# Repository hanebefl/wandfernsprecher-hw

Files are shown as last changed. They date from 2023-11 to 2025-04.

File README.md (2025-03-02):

# GSM Wandfernsprecher
GSM conversion PCB for an old German wall-mounted telephone.

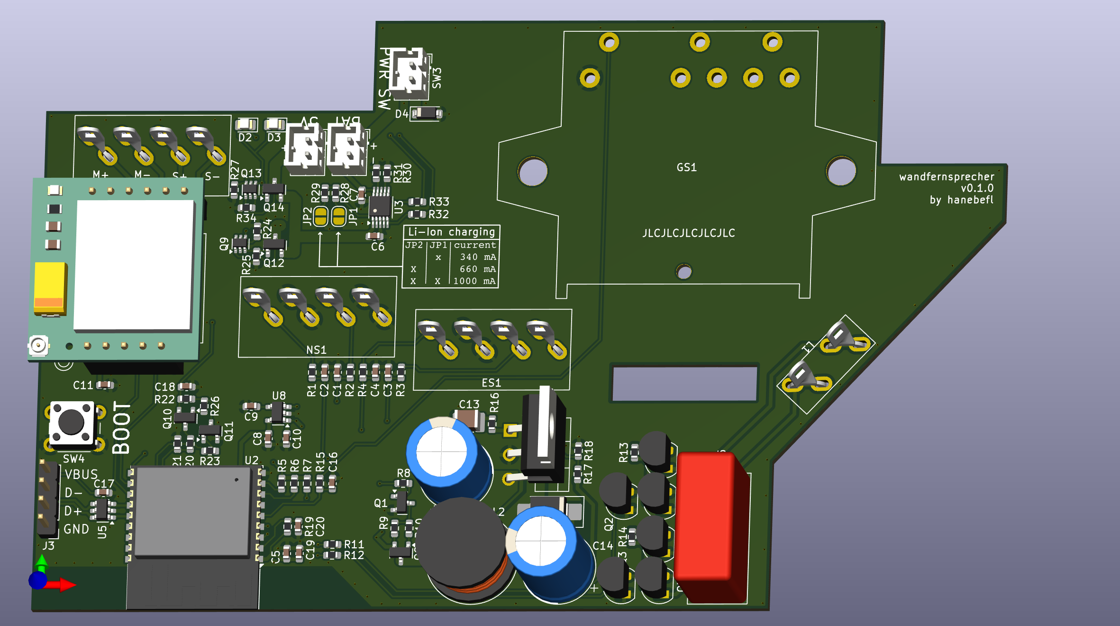
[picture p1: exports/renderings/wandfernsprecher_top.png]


This project uses a SIM800L GSM module, and is controlled by a ESP32-C3 running Micropython.

## Firmware Source Code
The firmware is located in a separate repository: [Wandfernsprecher Firmware](https://github.com/hanebefl/wandfernsprecher-fw)

## Directory Structure
| directory  | content |
|---|---|
| source | KiCad project directories |
| production | fabrication files (Gerber, BOM, placement) |
| exports | schematic and layout plots, board 3D model and renderings |
| datasheets | component datasheets |
| assets | board setups, component 3D models, logos |
| scripts | BOM export plugins, miscellaneous helper scripts for file conversion |
| hooks | git hooks, for example for automatic documentation export |

## Repository Template
Created with a [KiCAD project template](https://github.com/cyber-murmel/kicad-template) by [cyber-murmel](https://github.com/cyber-murmel)

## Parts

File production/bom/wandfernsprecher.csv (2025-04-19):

Designator | Footprint | Quantity | Value | LCSC Part #
C1,C2,C3,C4,C5,C11,C16,C10 | Capacitor_SMD:C_0603_1608Metric | 8 | 100nF
C17 | Capacitor_SMD:C_0603_1608Metric | 1 | 100n
C18,C20,C6,C7 | Capacitor_SMD:C_0603_1608Metric | 4 | 1µF
C19,C8 | Capacitor_SMD:C_0603_1608Metric | 2 | 10µF
D4 | Diode_SMD:D_SOD-123 | 1 | 5.1V
ES1 | FeWAp:CONN_01x04_vertical_mod | 1 | Erdschalter
GS1 | FeWAp:Gabelschalter | 1 | Gabelschalter
J1 | FeWAp:CONN_01x04_vertical_mod | 1 | Hörer
J3 | Connector_PinHeader_2.54mm:PinHeader_1x04_P2.54mm_Vertical | 1 | Conn_01x04
NS1 | FeWAp:CONN_01x04_vertical_mod | 1 | ~
Q10,Q8,Q12,Q14 | Package_TO_SOT_SMD:SOT-23 | 4 | AO3401A
Q11,Q15,Q1 | Package_TO_SOT_SMD:SOT-23 | 3 | AO3400A
R1,R2,R3,R4,R15 | Resistor_SMD:R_0603_1608Metric | 5 | 100
R5,R6,R7,R19,R21,R22,R9,R24,R25,R27,R31,R34 | Resistor_SMD:R_0603_1608Metric | 12 | 10k
R20 | Resistor_SMD:R_0603_1608Metric | 1 | 12k
R23,R26,R35,R8,R10,R16,R30 | Resistor_SMD:R_0603_1608Metric | 7 | 1k
SW4 | Button_Switch_THT:SW_PUSH_6mm | 1 | BOOT
U1 | FeWAp:SIM800L-module | 1 | SIM800L
U2 | RF_Module:ESP32-C3-WROOM-02 | 1 | ESP32-C3-WROOM-02
U5 | Package_TO_SOT_SMD:SOT-23-6 | 1 | USBLC6-2SC6
C12 | Capacitor_THT:CP_Radial_D10.0mm_P5.00mm | 1 | 100µF
C13 | Capacitor_SMD:C_1210_3225Metric_Pad1.33x2.70mm_HandSolder | 1 | 1µF
C14 | Capacitor_THT:CP_Radial_D10.0mm_P5.00mm | 1 | 220µF
C15 | Capacitor_THT:C_Rect_L18.0mm_W8.0mm_P15.00mm_FKS3_FKP3 | 1 | 1µF
D1 | Diode_SMD:D_SMB_Handsoldering | 1 | MBRS1100T3
L1 | FeWAp:CONN_01x02_vertical_mod | 1 | ~
L2 | Inductor_THT:L_Radial_D12.5mm_P7.00mm_Fastron_09HCP | 1 | L
Q2,Q3,Q4,Q6 | Package_TO_SOT_THT:TO-92_HandSolder | 4 | 2N5551
Q5,Q7 | Package_TO_SOT_THT:TO-92_HandSolder | 2 | 2N5401
R11,R12 | Resistor_SMD:R_0603_1608Metric | 2 | 2k2
R13,R14 | Resistor_SMD:R_0603_1608Metric | 2 | 47k
R17 | Resistor_SMD:R_0603_1608Metric | 1 | 68k
R18 | Resistor_SMD:R_0603_1608Metric | 1 | 1k8
U4 | Package_TO_SOT_THT:TO-220-5_P3.4x3.7mm_StaggerOdd_Lead3.8mm_Vertical | 1 | LT1170CT
BT1 | Connector_JST:JST_PH_B2B-PH-K_1x02_P2.00mm_Vertical | 1 | Battery_Cell
C9 | Capacitor_SMD:C_0603_1608Metric | 1 | 10nF
D2 | LED_SMD:LED_0805_2012Metric | 1 | GRN
D3 | LED_SMD:LED_0805_2012Metric | 1 | YEL
J2 | Connector_JST:JST_PH_B2B-PH-K_1x02_P2.00mm_Vertical | 1 | Vin
Q9,Q13 | Package_TO_SOT_SMD:SOT-363_SC-70-6 | 2 | BC857BS
R28,R32,R33 | Resistor_SMD:R_0603_1608Metric | 3 | 1k6
R29 | Resistor_SMD:R_0603_1608Metric | 1 | 820
SW3 | Connector_JST:JST_PH_B2B-PH-K_1x02_P2.00mm_Vertical | 1 | SW_SPST
U3 | Package_SO:HVSSOP-10-1EP_3x3mm_P0.5mm_EP1.57x1.88mm_ThermalVias | 1 | BQ24090DGQ
U8 | Package_TO_SOT_SMD:SOT-23-5 | 1 | TPS73633DBV

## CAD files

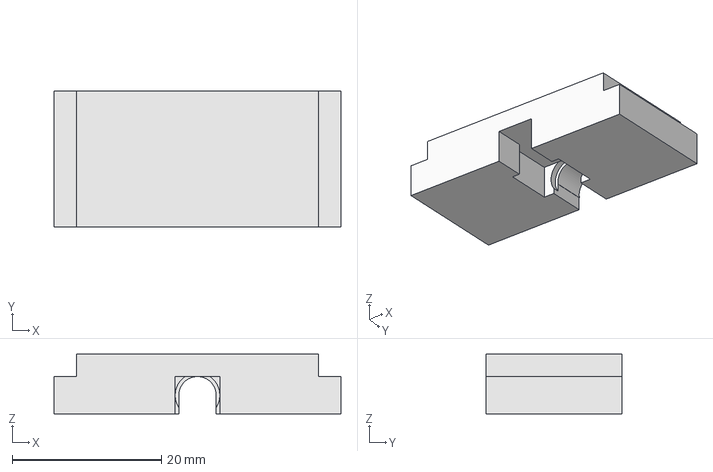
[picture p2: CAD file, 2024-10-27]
assets/3D models/FeWAp_switch_holder.FCStd
38.5 x 18.3 x 8.00 mm

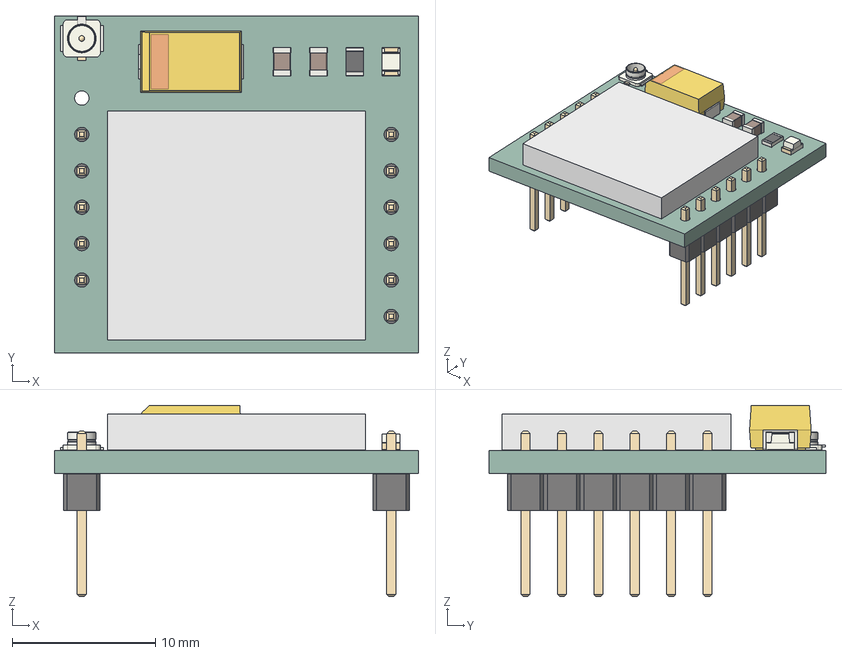
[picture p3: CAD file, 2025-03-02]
assets/SIM800-model/SIM800L-module.step
25.4 x 23.5 x 13.3 mm
LED_0805_2012Metric
R_0805_2012Metric
C_0805_2012Metric x 2
CP_EIA_7343_31_Kemet_D
U.FL_Hirose_U.FL-R-SMT-1_Vertical
PinHeader_1x05_P254mm_Vertical
PinHeader_1x06_P254mm_Vertical
sim800-model_PCB

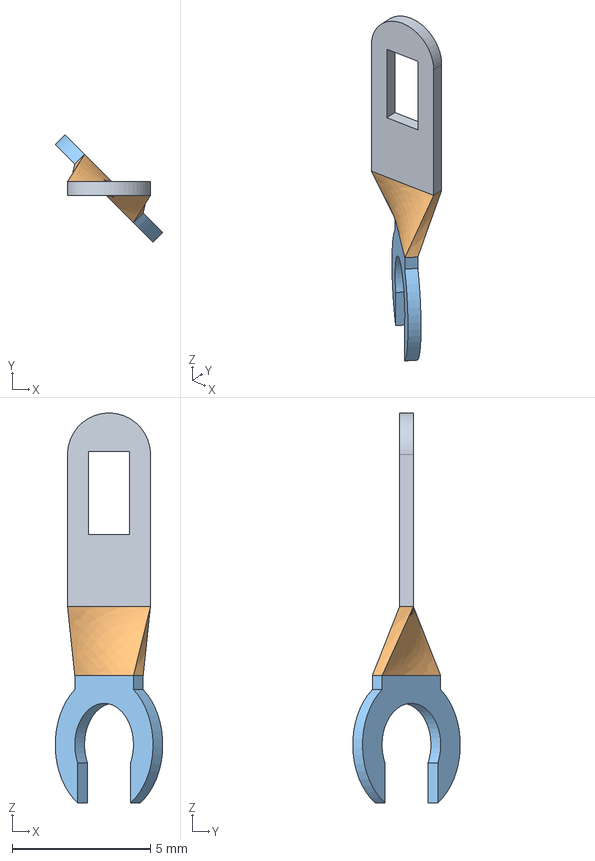
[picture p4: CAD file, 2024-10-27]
assets/3D models/pin_mod.step
3.89 x 3.89 x 14.1 mm

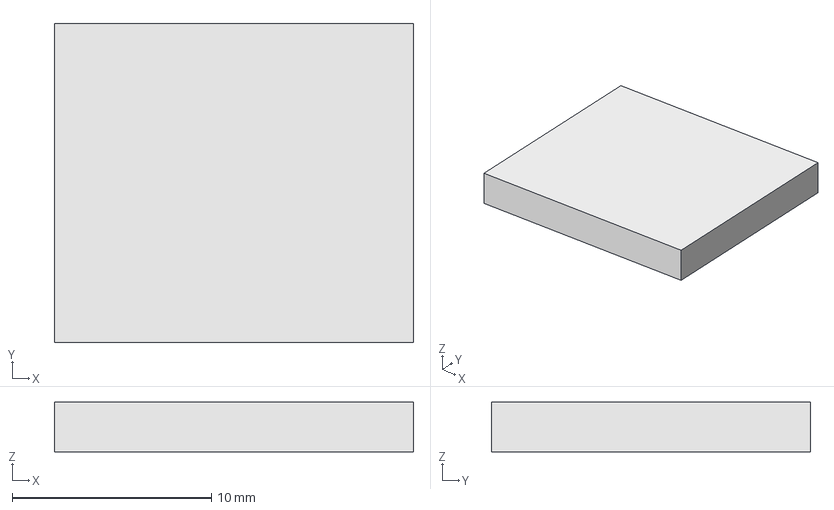
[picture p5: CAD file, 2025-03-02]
assets/SIM800-model/shield.step
18.0 x 16.0 x 2.50 mm

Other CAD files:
assets/3D models/pin-mod.FCStd
assets/3D models/pin_mod.stl

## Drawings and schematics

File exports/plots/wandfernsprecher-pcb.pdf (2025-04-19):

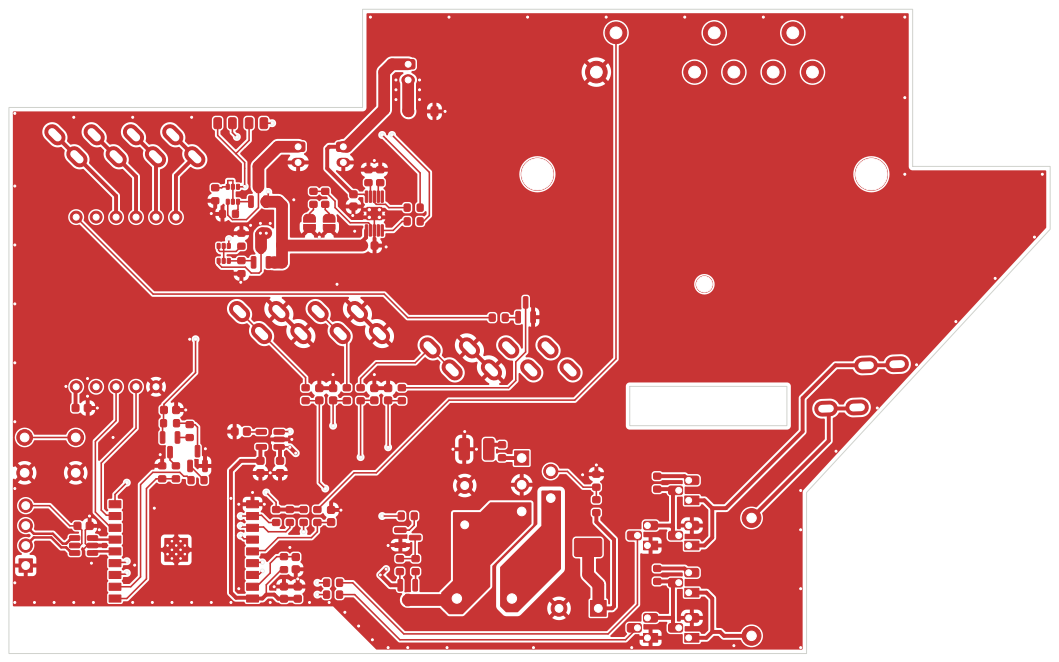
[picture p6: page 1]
D Date: 2024-11-01 KiCad; E.D.A. 8.0.9 Size: A4; Rev: 0.1.1; Id: 1/1 Title: Wandfernsprecher File: wandfernsprecher.kicad_pcb Sheet: author:; hanebefl Copyright; hanebefl (https://github.com/hanebefl)

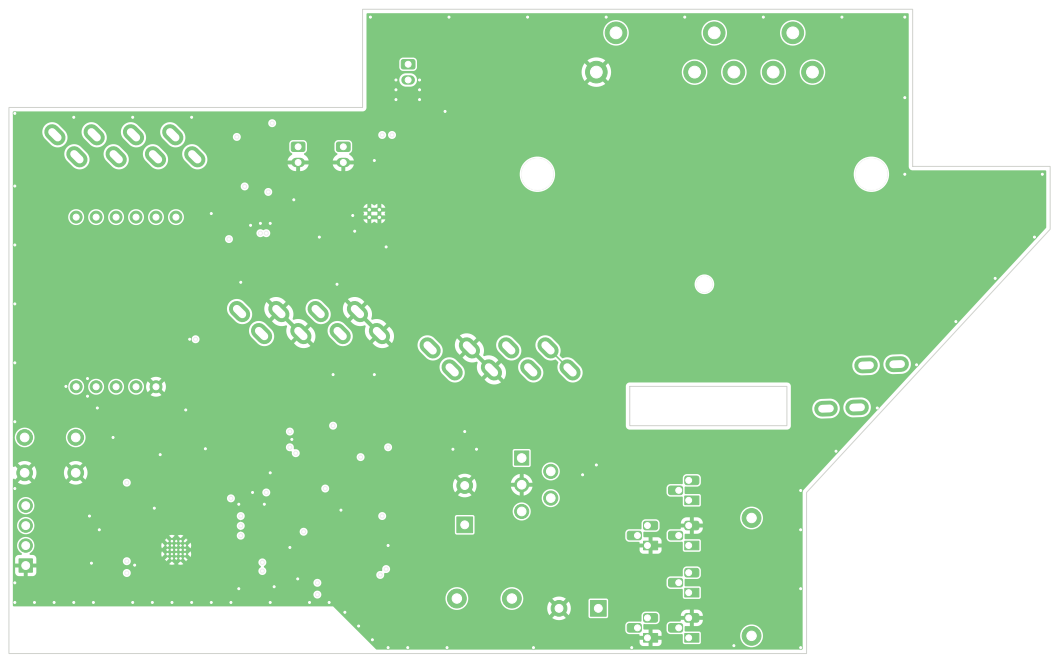
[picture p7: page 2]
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

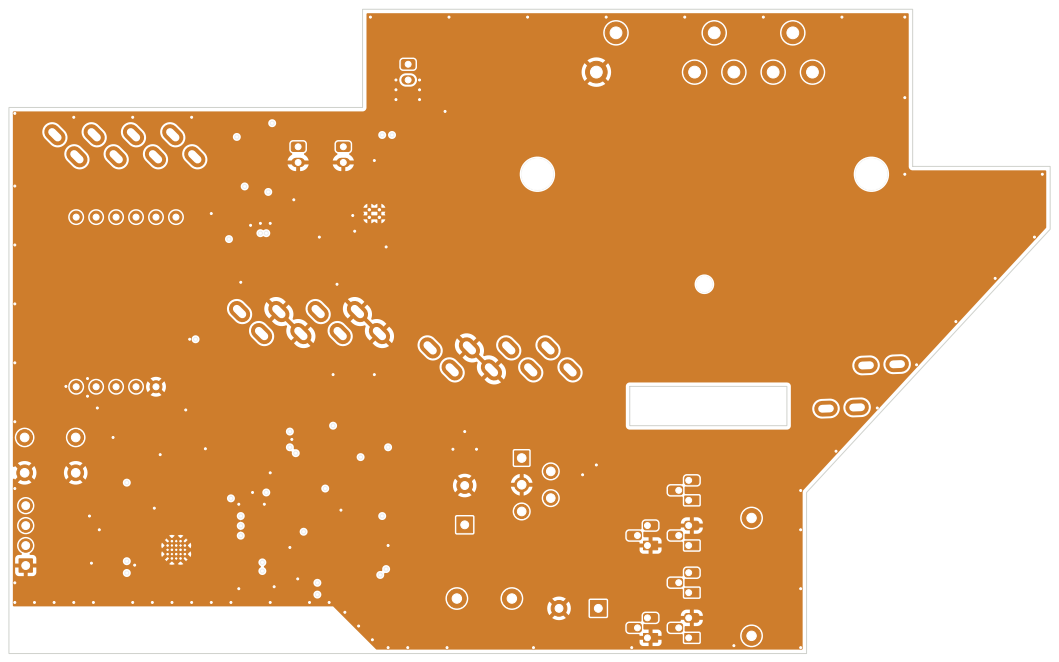
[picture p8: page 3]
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

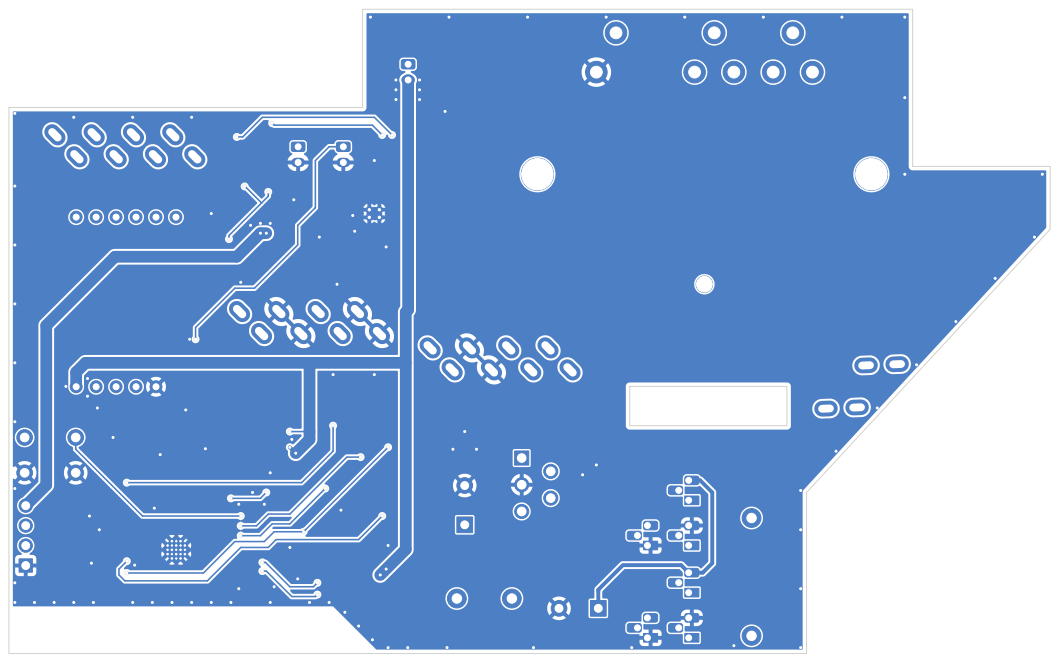
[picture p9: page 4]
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

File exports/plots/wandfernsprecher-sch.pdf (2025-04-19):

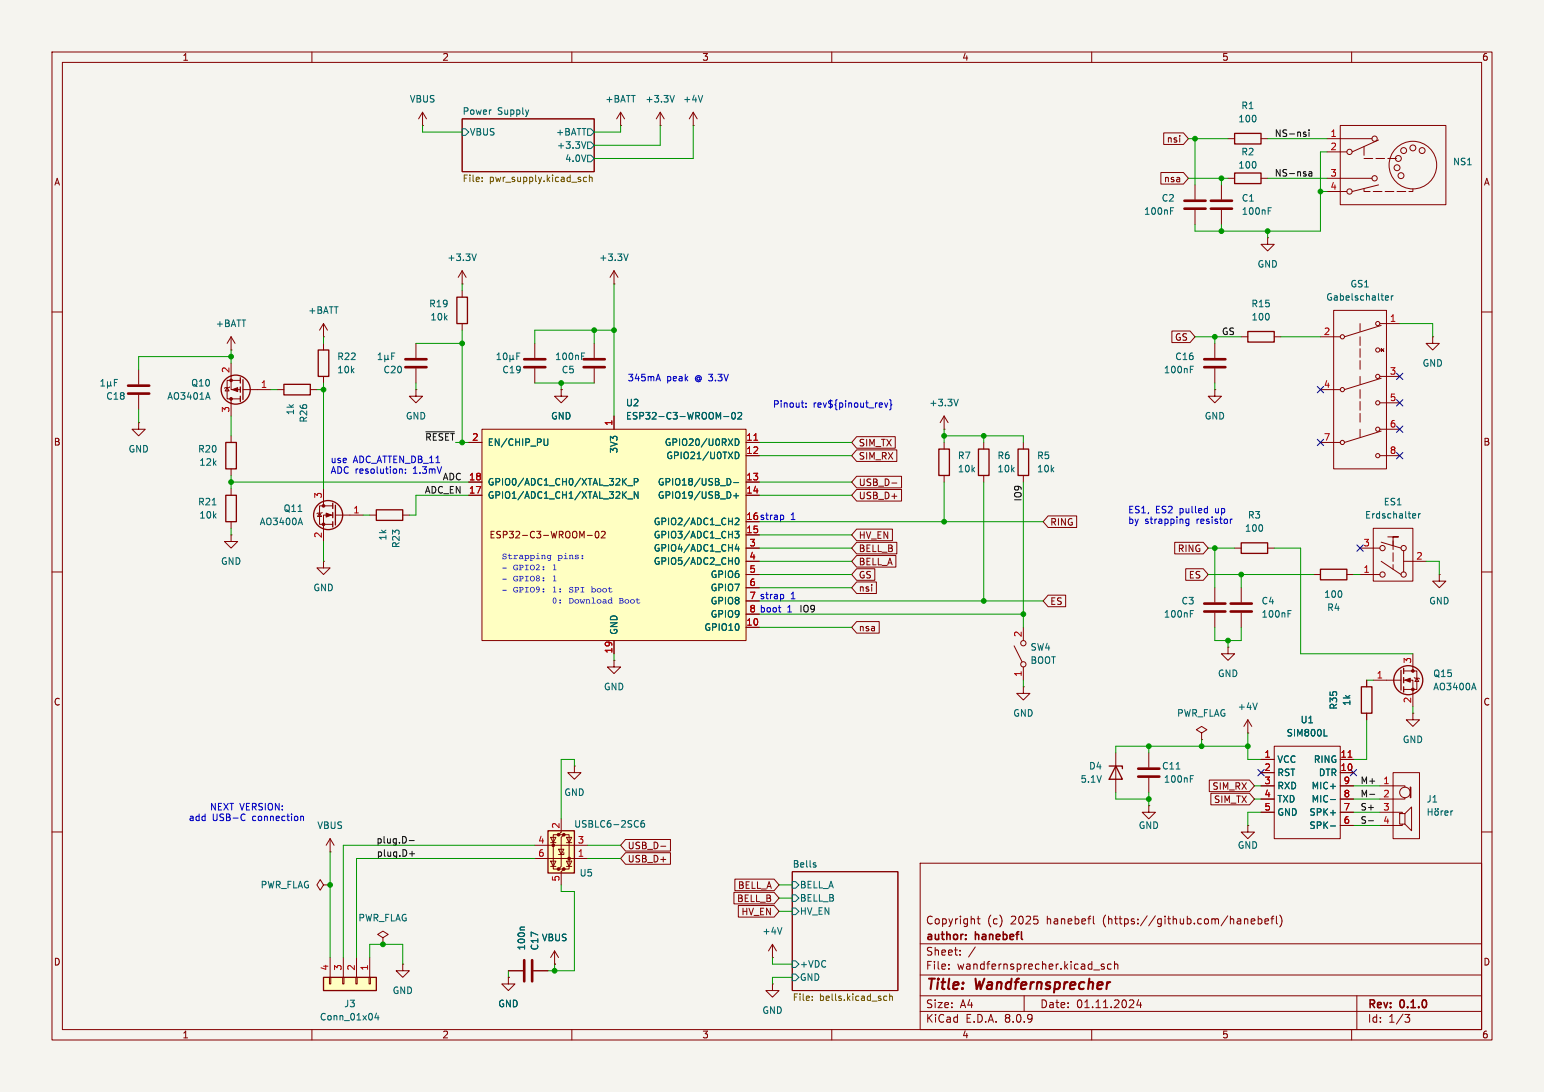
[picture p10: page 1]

- GPIO9: 1: SPI boot 0: Download Boot VBUS 100n C17 GND

1 GPIO10 10 GPIO20/U0RXD 11 GPIO21/U0TXD 12 GPIO18/USB_D- 13 GPIO19/USB_D+ 14 GPIO3/ADC1_CH3 15 GPIO2/ADC1_CH2 16 GPIO1/ADC1_CH1/XTAL_32K_N 17 GPIO0/ADC1_CH0/XTAL_32K_P 18 GND 19 EN/CHIP_PU 2 GPIO4/ADC1_CH4 3 GPIO5/ADC2_CH0 4 GPIO6 5 GPIO7 6 GPIO8 7 GPIO9 8 U2ESP32-C3-WROOM-02 GND GND

1 GPIO10 10 GPIO20/U0RXD 11 GPIO21/U0TXD 12 GPIO18/USB_D- 13 GPIO19/USB_D+ 14 GPIO3/ADC1_CH3 15 GPIO2/ADC1_CH2 16 GPIO1/ADC1_CH1/XTAL_32K_N 17 GPIO0/ADC1_CH0/XTAL_32K_P 18 GND 19 EN/CHIP_PU 2 GPIO4/ADC1_CH4 3 GPIO5/ADC2_CH0 4 GPIO6 5 GPIO7 6 GPIO8 7 GPIO9 8 R35 1k U1 SIM800L VCC 1 DTR 10 RING 11 RST 2 RXD 3 TXD 4 GND 5 SPK- 6 SPK+ 7 MIC- 8 MIC+ 9

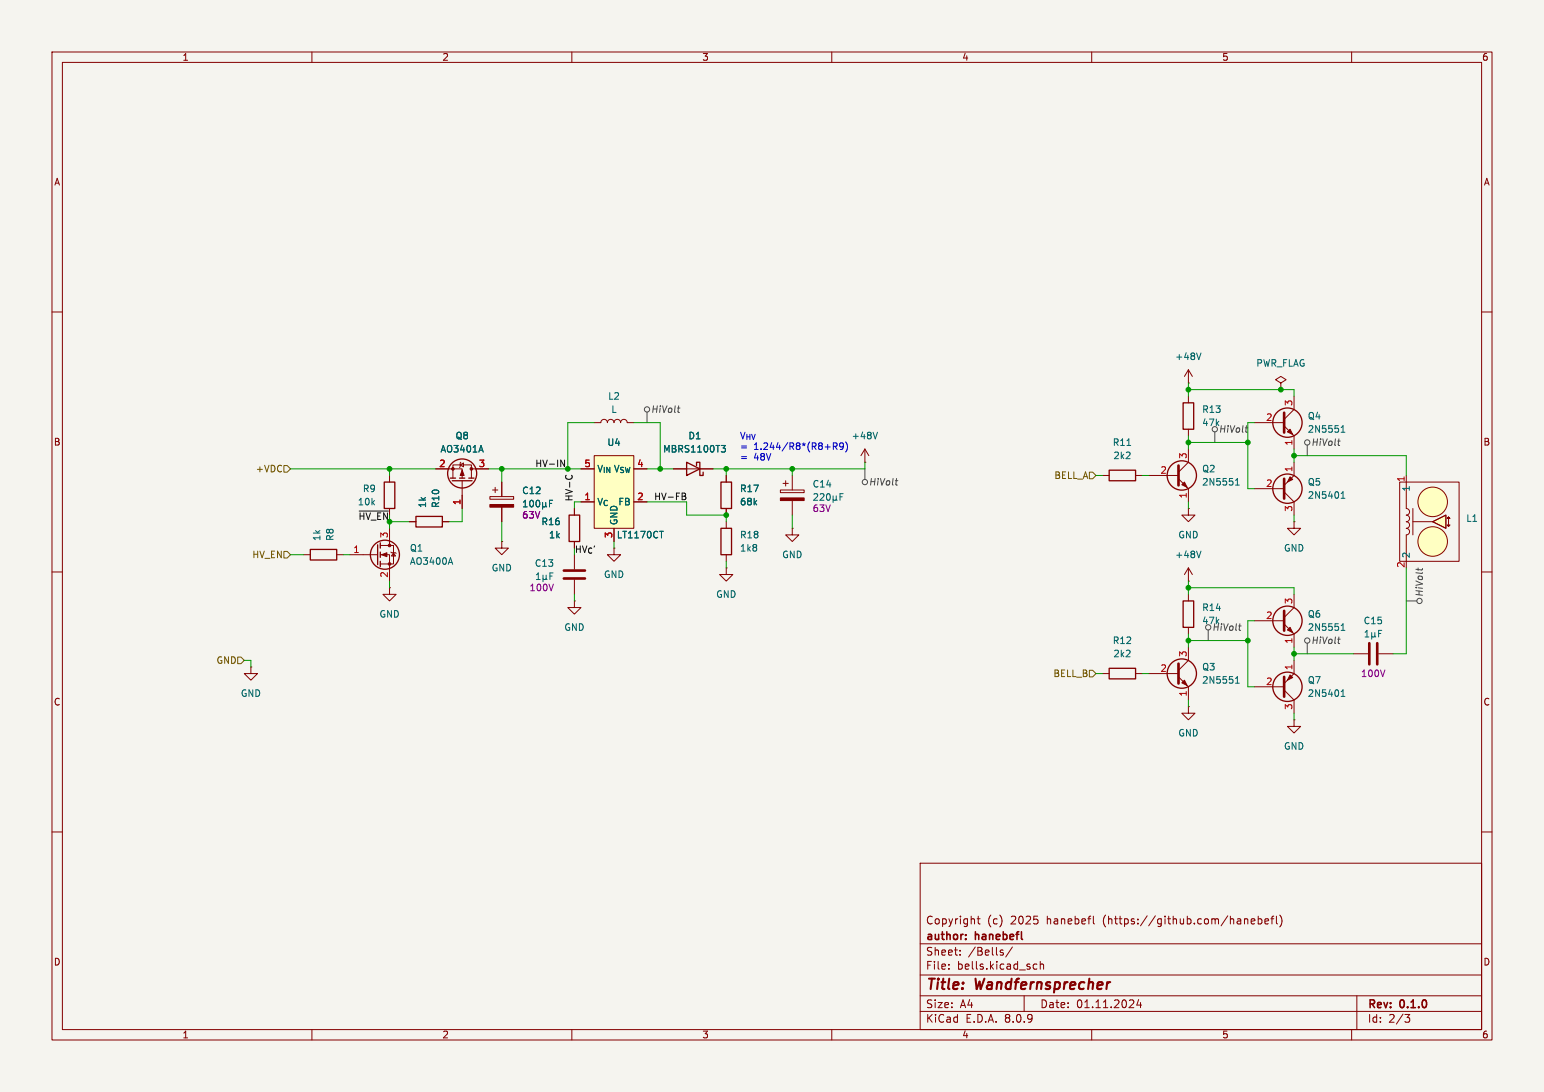
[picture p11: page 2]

BELL_A HV-FB HV-IN HV-C

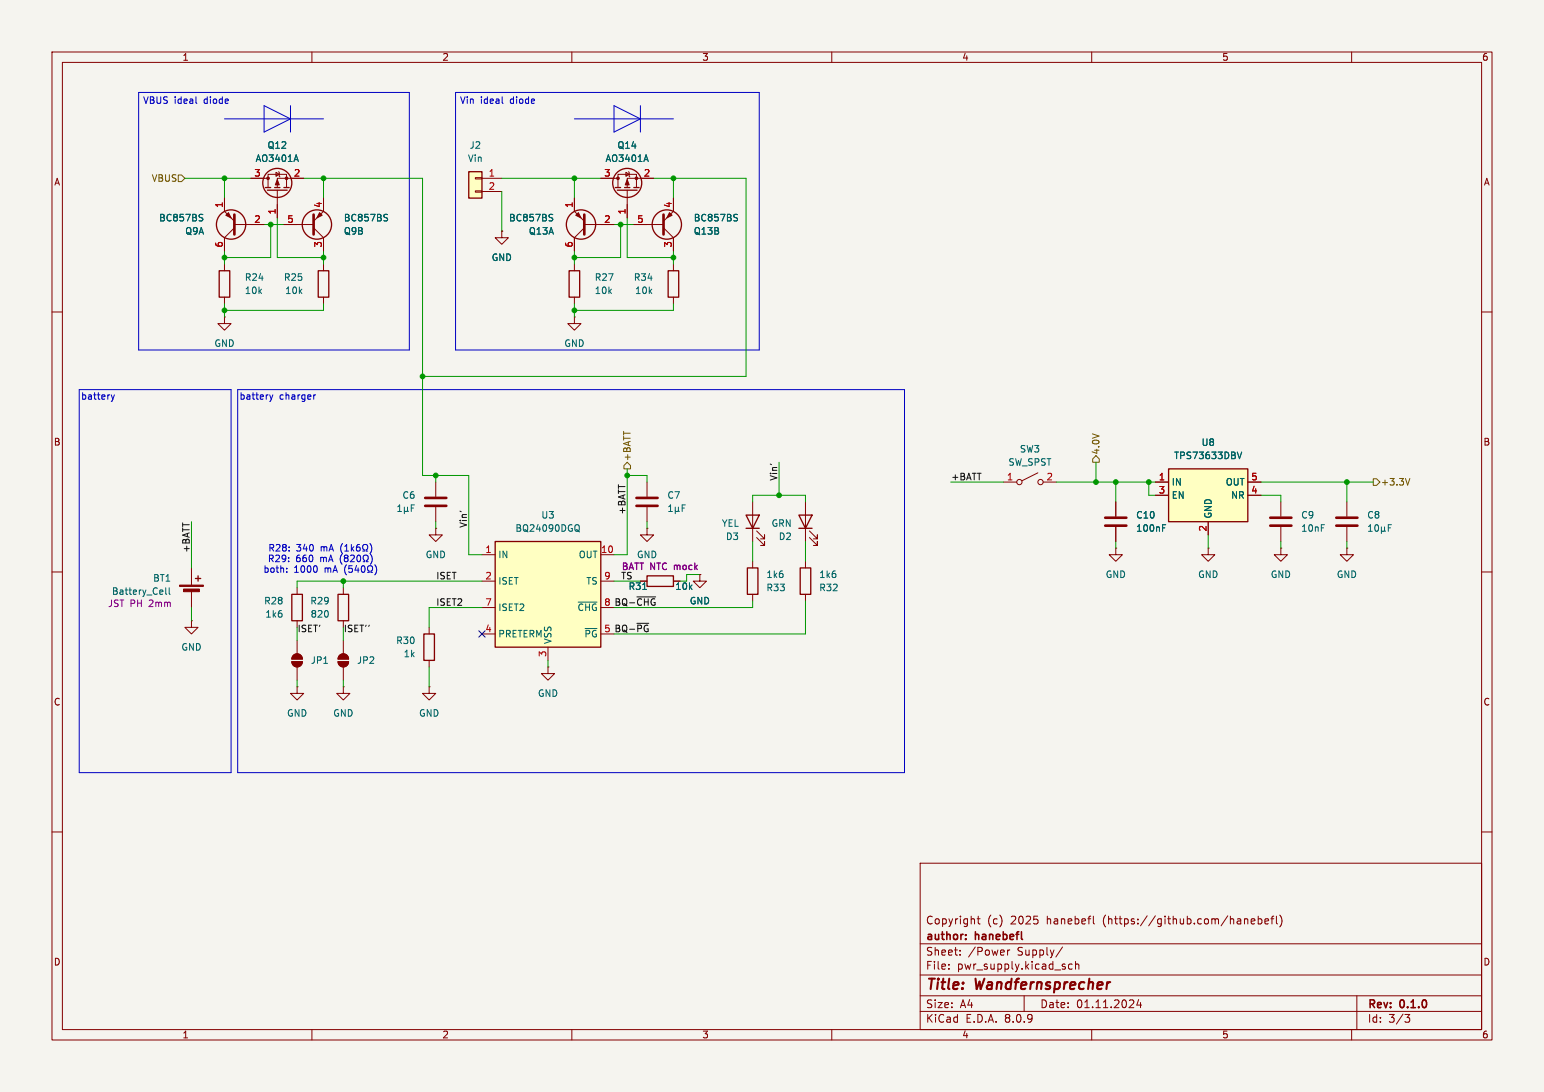
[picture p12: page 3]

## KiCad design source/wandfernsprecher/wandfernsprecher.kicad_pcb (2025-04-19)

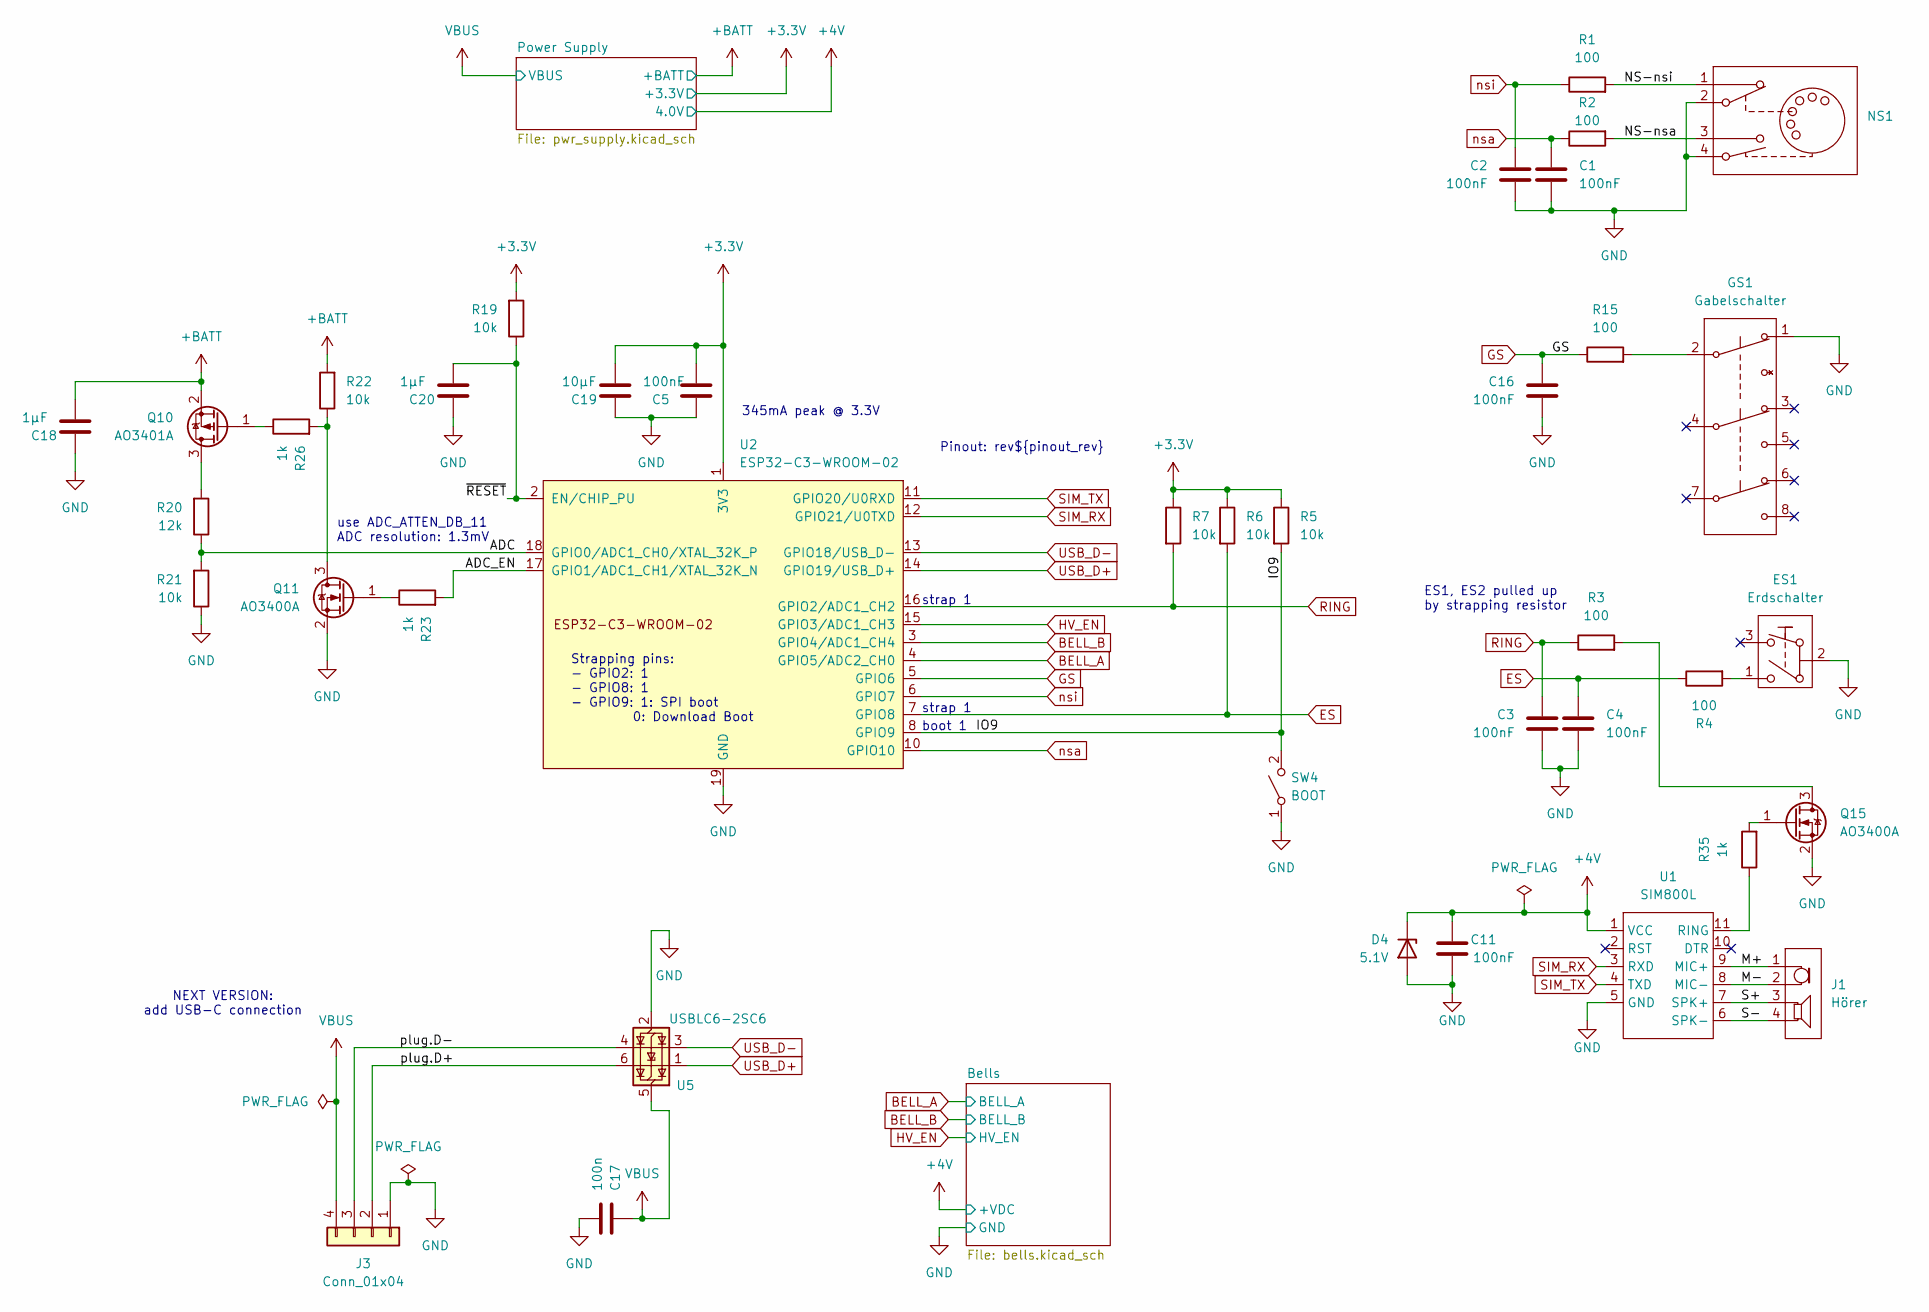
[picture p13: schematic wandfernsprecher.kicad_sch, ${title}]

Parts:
C1, C2, C3, C4, C5, C11, C16: 100nF; C_0603_1608Metric
C17: 100n; C_0603_1608Metric
C18, C20: 1µF; C_0603_1608Metric
C19: 10µF; C_0603_1608Metric
D4: 5.1V; D_SOD-123
ES1: Erdschalter; CONN_01x04_vertical_mod
GS1: Gabelschalter
J1: Hörer; CONN_01x04_vertical_mod
J3: Conn_01x04; PinHeader_1x04_P2.54mm_Vertical
NS1: CONN_01x04_vertical_mod
Q10: AO3401A; SOT-23
Q11, Q15: AO3400A; SOT-23
R1, R2, R3, R4, R15: 100; R_0603_1608Metric
R5, R6, R7, R19, R21, R22: 10k; R_0603_1608Metric
R20: 12k; R_0603_1608Metric
R23, R26, R35: 1k; R_0603_1608Metric
SW4: BOOT; SW_PUSH_6mm
U1: SIM800L; SIM800L-module
U2: ESP32-C3-WROOM-02
U5: USBLC6-2SC6; SOT-23-6

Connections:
+3.3V: C5.2, C19.2, R5.1, R6.1, R7.1, R19.2, U2.1 (3V3); also elsewhere on the board
+4V: C11.1, D4.1 (K), U1.1 (VCC); also elsewhere on the board
+BATT: C18.2, Q10.2 (S), R22.2; also elsewhere on the board
/ADC: R20.1, R21.2, U2.18 (GPIO0/ADC1_CH0/XTAL_32K_P)
/ADC_EN: R23.2, U2.17 (GPIO1/ADC1_CH1/XTAL_32K_N)
/IO9: R5.2, SW4.2 (B), U2.8 (GPIO9)
/M+: J1.1 (SPK+), U1.9 (MIC+)
/M-: J1.2 (SPK-), U1.8 (MIC-)
/NS-nsa: NS1.3 (E1), R2.2
/NS-nsi: NS1.1 (N1), R1.2
/S+: J1.3 (MIC+), U1.7 (SPK+)
/S-: J1.4 (MIC-), U1.6 (SPK-)
/plug.D+: J3.2, U5.6 (I/O1)
/plug.D-: J3.3, U5.4 (I/O2)
/~RESET: C20.2, R19.1, U2.2 (EN/CHIP_PU)
BELL_A: U2.4 (GPIO5/ADC2_CH0); also elsewhere on the board
BELL_B: U2.3 (GPIO4/ADC1_CH4); also elsewhere on the board
ES: C4.1, R4.1, R6.2, U2.7 (GPIO8)
GND: C1.2, C2.2, C3.2, C4.2, C5.1, C11.2, C16.2, C17.2, C18.1, C19.1, C20.1, D4.2 (A), ES1.2 (B), GS1.1 (S1l), J3.1, NS1.2 (N2), NS1.4 (E2), Q11.2 (S), Q15.2 (S), R21.1, SW4.1 (A), U1.5 (GND), U2.9 (GND), U2.19 (GND), U5.2 (GND); also elsewhere on the board
GS: C16.1, R15.1, U2.5 (GPIO6)
HV_EN: U2.15 (GPIO3/ADC1_CH3); also elsewhere on the board
unnamed: ES1.1 (A), R4.2
unnamed: GS1.2 (S1c), R15.2
unnamed: Q10.3 (D), R20.2
unnamed: Q10.1 (G), R26.1
unnamed: Q11.3 (D), R22.1, R26.2
unnamed: Q11.1 (G), R23.1
unnamed: Q15.3 (D), R3.2
unnamed: Q15.1 (G), R35.2
unnamed: R35.1, U1.11 (RING)
RING: C3.1, R3.1, R7.2, U2.16 (GPIO2/ADC1_CH2)
SIM_RX: U1.3 (RXD), U2.12 (GPIO21/U0TXD)
SIM_TX: U1.4 (TXD), U2.11 (GPIO20/U0RXD)
USB_D+: U2.14 (GPIO19/USB_D+), U5.1 (I/O1)
USB_D-: U2.13 (GPIO18/USB_D-), U5.3 (I/O2)
VBUS: C17.1, J3.4, U5.5 (VBUS); also elsewhere on the board
nsa: C1.1, R2.1, U2.10 (GPIO10)
nsi: C2.1, R1.1, U2.6 (GPIO7)

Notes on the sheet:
NEXT VERSION: add USB-C connection
Pinout: rev${pinout_rev}
strap 1
boot 1
ES1, ES2 pulled up by strapping resistor
Strapping pins: - GPIO2: 1 - GPIO8: 1 - GPIO9: 1: SPI boot 0: Download Boot
345mA peak @ 3.3V
use ADC_ATTEN_DB_11 ADC resolution: 1.3mV

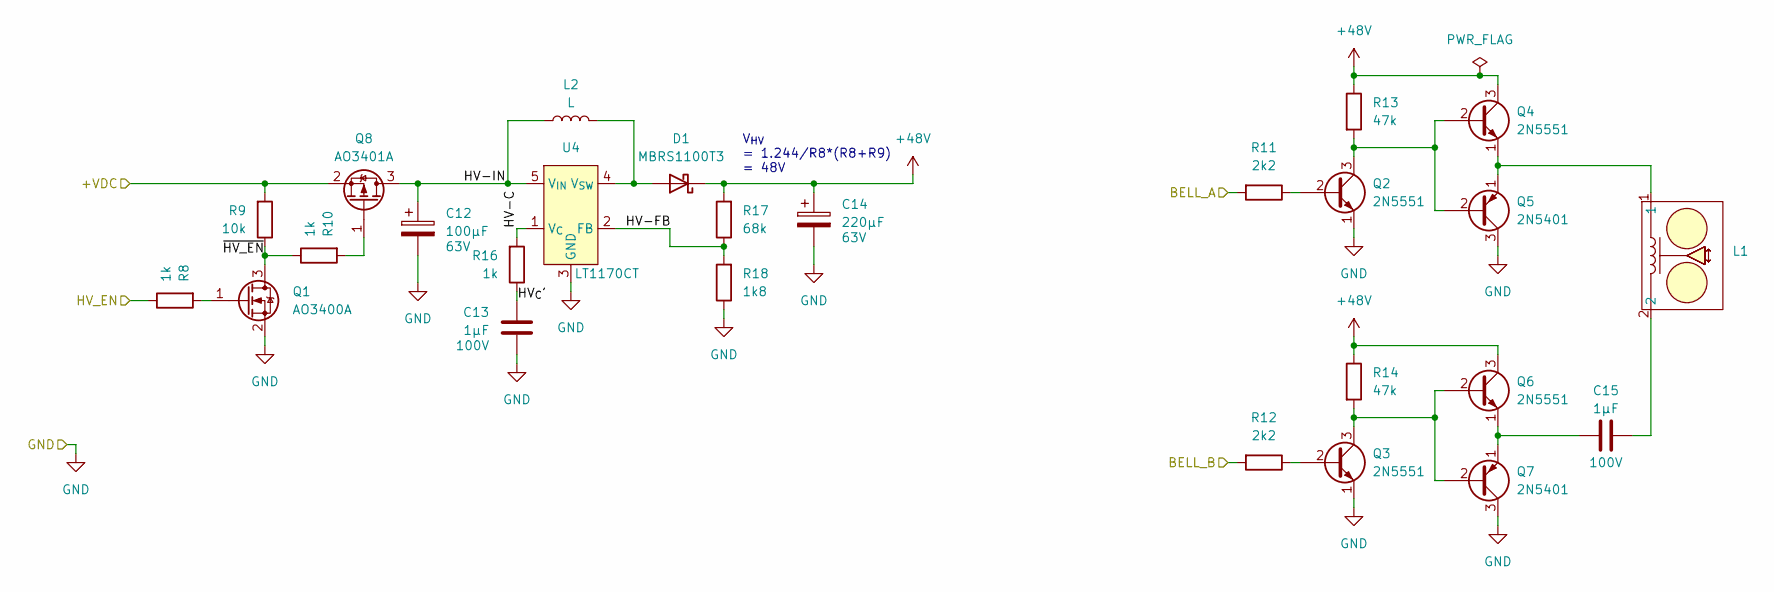
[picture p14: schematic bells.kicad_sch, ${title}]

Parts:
C12: 100µF; CP_Radial_D10.0mm_P5.00mm; Voltage 63V
C13: 1µF; C_1210_3225Metric_Pad1.33x2.70mm_HandSolder; Voltage 100V
C14: 220µF; CP_Radial_D10.0mm_P5.00mm; Voltage 63V
C15: 1µF; C_Rect_L18.0mm_W8.0mm_P15.00mm_FKS3_FKP3; Voltage 100V
D1: MBRS1100T3; D_SMB_Handsoldering
L1: CONN_01x02_vertical_mod
L2: L; L_Radial_D12.5mm_P7.00mm_Fastron_09HCP
Q1: AO3400A; SOT-23
Q2, Q3, Q4, Q6: 2N5551; TO-92_HandSolder
Q5, Q7: 2N5401; TO-92_HandSolder
Q8: AO3401A; SOT-23
R8, R10, R16: 1k; R_0603_1608Metric
R9: 10k; R_0603_1608Metric
R11, R12: 2k2; R_0603_1608Metric
R13, R14: 47k; R_0603_1608Metric
R17: 68k; R_0603_1608Metric
R18: 1k8; R_0603_1608Metric
U4: LT1170CT; TO-220-5_P3.4x3.7mm_StaggerOdd_Lead3.8mm_Vertical

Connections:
+4V: Q8.2 (S), R9.2; also elsewhere on the board
+48V: C14.1, D1.1 (K), Q4.3 (C), Q6.3 (C), R13.1, R14.1, R17.2
/Bells/HV-C: R16.2, U4.1 (V_{C})
/Bells/HV-FB: R17.1, R18.2, U4.2 (FB)
/Bells/HV-IN: C12.1, L2.1, Q8.3 (D), U4.5 (V_{IN})
/Bells/HV_{C}': C13.1, R16.1
/Bells/~HV_EN: Q1.3 (D), R9.1, R10.1
BELL_A: R11.2; also elsewhere on the board
BELL_B: R12.2; also elsewhere on the board
GND: C12.2, C13.2, C14.2, Q1.2 (S), Q2.1 (E), Q3.1 (E), Q5.3 (C), Q7.3 (C), R18.1, U4.3 (GND); also elsewhere on the board
HV_EN: R8.1; also elsewhere on the board
unnamed: C15.2, L1.2
unnamed: D1.2 (A), L2.2, U4.4 (V_{SW})
unnamed: Q1.1 (G), R8.2
unnamed: Q2.2 (B), R11.1
unnamed: Q2.3 (C), Q4.2 (B), Q5.2 (B), R13.2
unnamed: Q3.2 (B), R12.1
unnamed: Q3.3 (C), Q6.2 (B), Q7.2 (B), R14.2
unnamed: L1.1, Q4.1 (E), Q5.1 (E)
unnamed: C15.1, Q6.1 (E), Q7.1 (E)
unnamed: Q8.1 (G), R10.2

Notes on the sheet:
V_{HV} = 1.244/R8*(R8+R9) = 48V

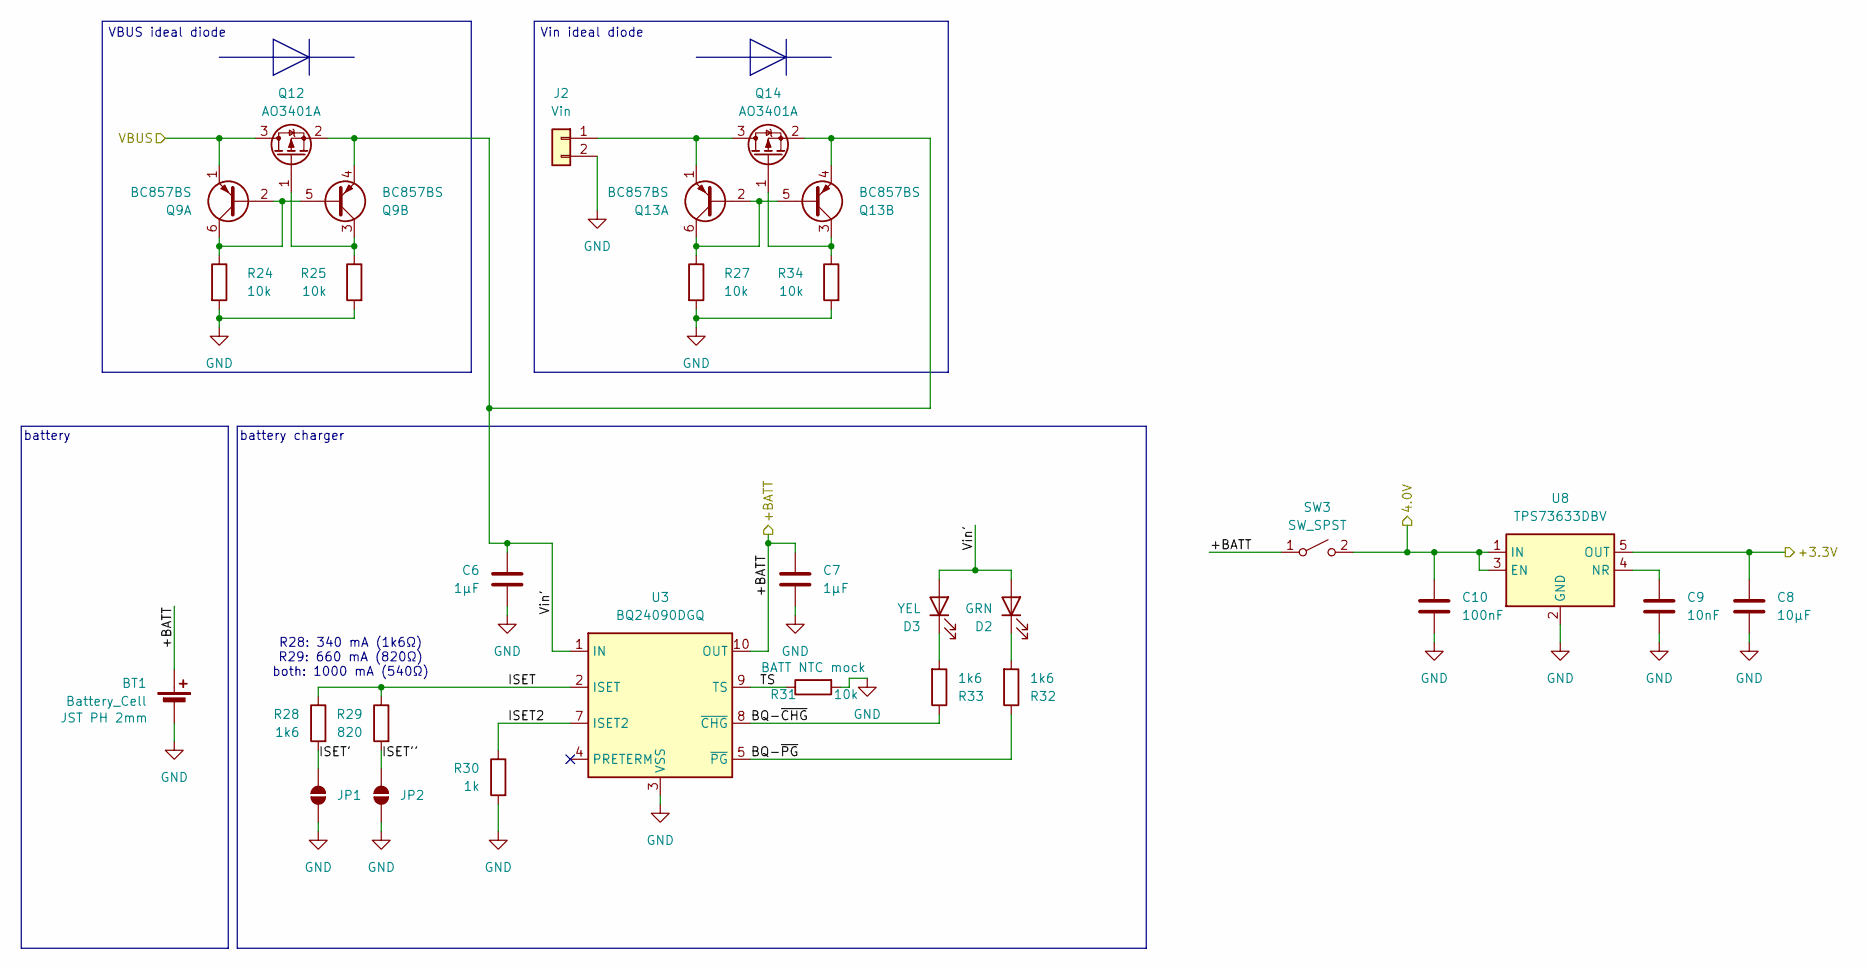
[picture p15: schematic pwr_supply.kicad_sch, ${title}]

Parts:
BT1: Battery_Cell; JST_PH_B2B-PH-K_1x02_P2.00mm_Vertical
C6, C7: 1µF; C_0603_1608Metric
C8: 10µF; C_0603_1608Metric
C9: 10nF; C_0603_1608Metric
C10: 100nF; C_0603_1608Metric
D2: GRN; LED_0805_2012Metric
D3: YEL; LED_0805_2012Metric
J2: Vin; JST_PH_B2B-PH-K_1x02_P2.00mm_Vertical
JP1, JP2: SolderJumper_2_Open; SolderJumper-2_P1.3mm_Open_RoundedPad1.0x1.5mm
Q9, Q13: BC857BS; SOT-363_SC-70-6
Q12, Q14: AO3401A; SOT-23
R24, R25, R27, R31, R34: 10k; R_0603_1608Metric
R28, R32, R33: 1k6; R_0603_1608Metric
R29: 820; R_0603_1608Metric
R30: 1k; R_0603_1608Metric
SW3: SW_SPST; JST_PH_B2B-PH-K_1x02_P2.00mm_Vertical
U3: BQ24090DGQ; HVSSOP-10-1EP_3x3mm_P0.5mm_EP1.57x1.88mm_ThermalVias
U8: TPS73633DBV; SOT-23-5

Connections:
+3.3V: C8.1, U8.5 (OUT); also elsewhere on the board
+4V: C10.1, SW3.2 (B), U8.1 (IN), U8.3 (EN); also elsewhere on the board
+BATT: BT1.1 (+), C7.1, SW3.1 (A), U3.10 (OUT); also elsewhere on the board
/Power Supply/BQ-~CHG: R33.1, U3.8 (~CHG)
/Power Supply/BQ-~PG: R32.1, U3.5 (~PG)
/Power Supply/ISET: R28.1, R29.1, U3.2 (ISET)
/Power Supply/ISET2: R30.1, U3.7 (ISET2)
/Power Supply/ISET': JP1.2 (B), R28.2
/Power Supply/ISET'': JP2.2 (B), R29.2
/Power Supply/TS: R31.1, U3.9 (TS)
/Power Supply/Vin': C6.1, D2.2 (A), D3.2 (A), Q9.4 (E2), Q12.2 (S), Q13.4 (E2), Q14.2 (S), U3.1 (IN)
GND: BT1.2 (-), C6.2, C7.2, C8.2, C9.2, C10.2, J2.2, JP1.1 (A), JP2.1 (A), R24.2, R25.2, R27.2, R30.2, R31.2, R34.2, U3.3 (VSS), U3.11 (VSS), U8.2 (GND); also elsewhere on the board
unnamed: D2.1 (K), R32.2
unnamed: D3.1 (K), R33.2
unnamed: J2.1, Q13.1 (E1), Q14.3 (D)
unnamed: Q9.2 (B1), Q9.5 (B2), Q9.6 (C1), R24.1
unnamed: Q9.3 (C2), Q12.1 (G), R25.1
unnamed: Q13.2 (B1), Q13.5 (B2), Q13.6 (C1), R27.1
unnamed: Q13.3 (C2), Q14.1 (G), R34.1
unnamed: C9.1, U8.4 (NR)
VBUS: Q9.1 (E1), Q12.3 (D); also elsewhere on the board

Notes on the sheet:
battery
Vin ideal diode
battery charger
R28: 340 mA (1k6Ω) R29: 660 mA (820Ω) both: 1000 mA (540Ω)
VBUS ideal diode

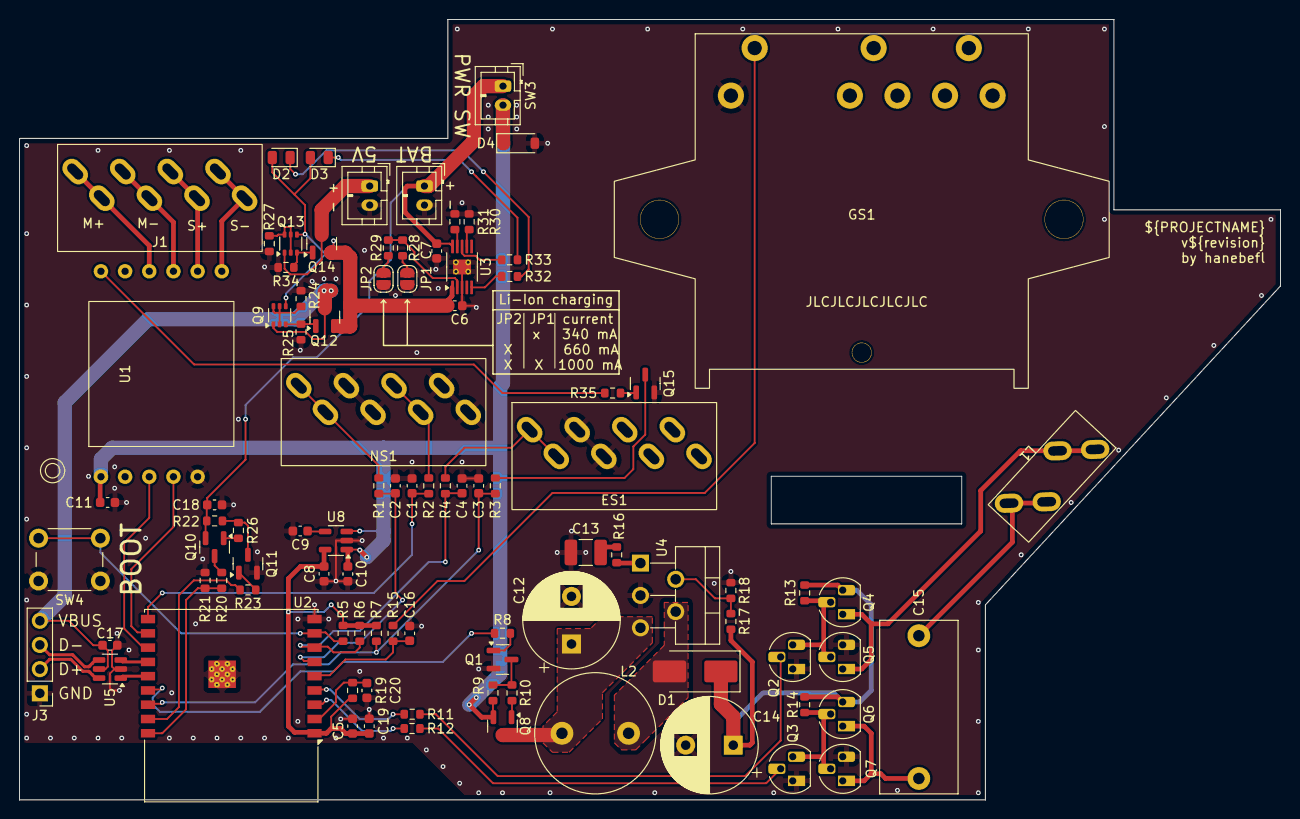
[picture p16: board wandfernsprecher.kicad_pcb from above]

Board: 4 copper layers, 132.5 x 82.0 mm, 93 parts (0 on the bottom side), 70 nets.

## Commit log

2024-10-05 added espressif kicad-libraries moved source to subfolder for make process added lockfile to .gitignore
    [bells.kicad_sch, pwr_supply.kicad_sch, template.kicad_pcb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]
2024-10-27 completed layout
    [bells.kicad_sch, pwr_supply.kicad_sch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]
2024-10-27 added ibom added switch holder FreeCAD file added Vin header and ideal diodes, finalized layout
    [FeWAp_switch_holder.FCStd, pin_mod.step, pwr_supply.kicad_sch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]
2024-11-01 Version 0.1.0
    [wandfernsprecher-B.Cu.gbr, wandfernsprecher-B.Mask.gbr, wandfernsprecher-B.Paste.gbr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]
2025-03-02 cleanup and 3D-Models fixed submodule updated README
    [SIM800L-module.step, bells.kicad_sch, pin-mod.FCStd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]
2025-03-02 Added MIT License
    [bells.kicad_sch, pwr_supply.kicad_sch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]
2025-04-19 connected RING interrupt line from GSM to ESP
    [wandfernsprecher-B.Cu.gbr, wandfernsprecher-B.Mask.gbr, wandfernsprecher-B.Paste.gbr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]
2025-04-19 pushed minor version
    [wandfernsprecher-B.Cu.gbr, wandfernsprecher-B.Mask.gbr, wandfernsprecher-B.Paste.gbr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]

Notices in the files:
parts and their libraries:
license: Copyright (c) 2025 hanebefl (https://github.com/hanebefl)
